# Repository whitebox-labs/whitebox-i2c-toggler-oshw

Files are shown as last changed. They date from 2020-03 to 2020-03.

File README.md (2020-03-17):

# I2C Toggler

The I2C Toggler is a small device to assist in switching the bus mode of Atlas Scientific EZO circuits between UART and I2C.

The EZO circuits bus mode can be switched by shorting certain pins upon power-up of the EZO-circuit. Repeating the process will switch the modes between UART and I2C back and forth. Pins must be shorted before power-up and stay shorted. The EZO's LED will fade to another color (depending on mode).

The EZO RTD circuit is switched by shorting PRB to TX.
All other EZO circuits (pH, EC, DO, ORP) are switched by shorting PGND to TX.

The I2C Toggler has an EZO connector (two 1x3 female headers) to plug an EZO circuit. It has a tactile switch to select wether to operate on an RTD or another circuit (to select which pins get shorted). A momentary button, to actually power on the circuit and change its bus mode. The Bus Switcher itself is powered by plugging it into an USB port - the PCB itself is shaped like the inside of a male USB plug.

How to operate the I2C Toggler:
1. select EZO circuit type (RTD or other)
2. Put EZO circuit on to Bus Switcher
3. Plug Bus Switcher into USB-port
4. Press and hold button until EZO circuit boots up and changes the LED color
5. Release the button (which cuts power to the EZO circuit)

## License
Hardware design files and documentation are licensed under Attribution-ShareAlike 4.0 International (CC BY-SA 4.0)
https://creativecommons.org/licenses/by-sa/4.0/

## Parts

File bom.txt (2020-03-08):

D101: Fairchild BAT54C
STP (1/2): 1x3 female pin header 2.54 pitch
STP (2/2): 1x3 female pin header 2.54 pitch
SW102: C&K JS202011JCQN 
SW101: Würth 434123043816

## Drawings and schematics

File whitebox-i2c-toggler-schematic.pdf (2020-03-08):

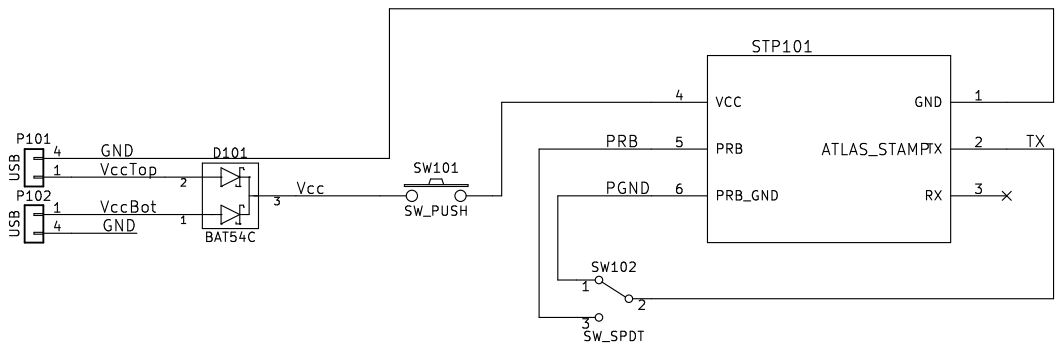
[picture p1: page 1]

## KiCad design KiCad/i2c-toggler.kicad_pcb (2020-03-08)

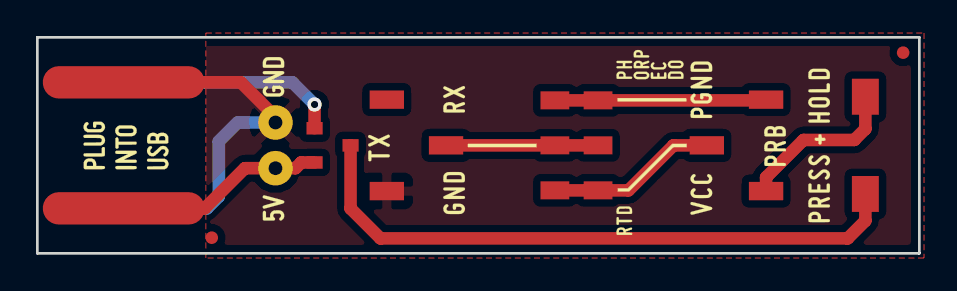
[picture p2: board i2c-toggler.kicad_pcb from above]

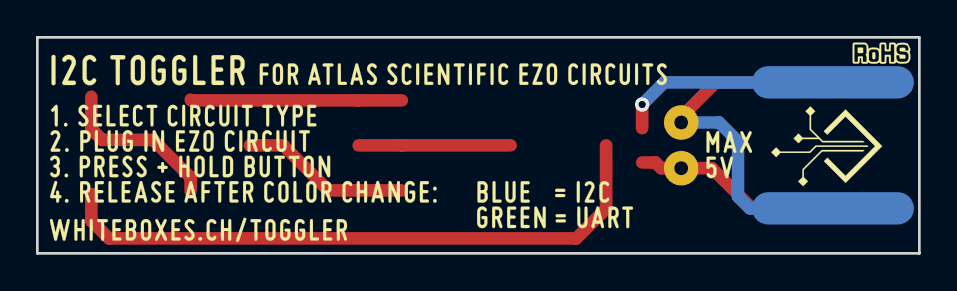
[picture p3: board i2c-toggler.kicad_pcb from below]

Board: 2 copper layers, 49.0 x 12.0 mm, 10 parts (2 on the bottom side), 8 nets.

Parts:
D101: BAT54C; WL-SOT23-3
GBOT: LOGO; WL-silks-BOT
GTOP: LOGO; WL-silks-TOP
P101: USB; WL-usb-A-TOP
P102: USB; WL-usb-A-BOT
STP101: ATLAS_STAMP; WL-EZO-13380
SW101: SW_PUSH; WL-WE434123043816
SW102: SW_SPDT; WL-JS202011JCQN
fiducial: VAL**; WL-fiducial_0.75mm
fiducial#2: VAL**; WL-fiducial_0.75mm

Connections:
/GND: P101.4, P102.4, STP101.1
/PGND: STP101.6, SW102.1
/PRB: STP101.5, SW102.3
/TX: STP101.2, SW102.2
/Vcc: D101.3, SW101.1
/VccBot: D101.1, P102.1
/VccTop: D101.2, P101.1
unnamed: STP101.4, SW101.2

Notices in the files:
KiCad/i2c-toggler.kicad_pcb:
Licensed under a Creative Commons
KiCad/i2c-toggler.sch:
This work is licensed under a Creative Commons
